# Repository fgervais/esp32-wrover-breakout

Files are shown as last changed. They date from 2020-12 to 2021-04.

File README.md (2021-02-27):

# Objective

The goal of this project is to make a lower cost esp32 module than the TinyPICO
for my other projects.

The TinyPICO is great. It is small and uses low current in deep sleep but it
costs me about 40$ CAD once it reaches me. I'd prefer if I could have something
at around 10$ CAD which is the goal of this project.

# Breadboard Version

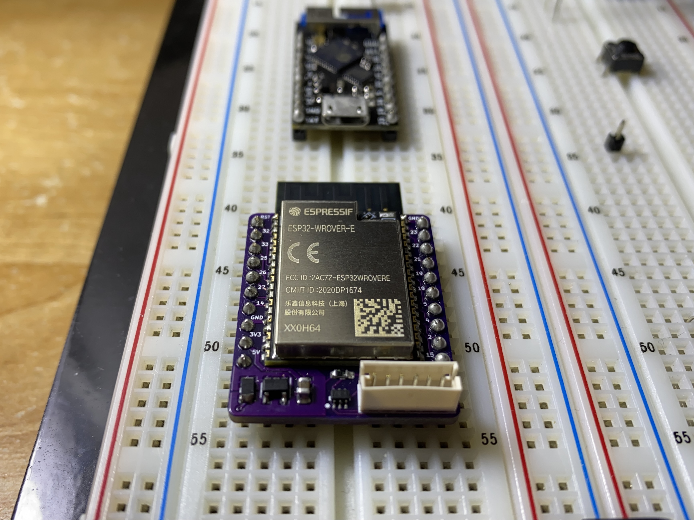
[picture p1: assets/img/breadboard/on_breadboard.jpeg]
On Breadboard


## Price

The bare PCB costs 2.67$ CAD from OSH Park.
Digikey BOM cost for 1 unit is 8.09$ CAD.

Total is 10.76$ CAD (worst case)

## PCB

[OSH Park](https://oshpark.com/shared_projects/hciJOsgc)

## BOM

[Digikey BOM](https://www.digikey.ca/BOM/Create/CreateSharedBom?bomId=8507784)

## Programming

The programming is done through the JST connector using the 
[Adafruit 3309](https://www.adafruit.com/product/3309) along
with the following adapter:

- [Github](https://github.com/fgervais/project-adafruit-3309-adapter/tree/master/hardware/jst-zh)
- [OSH Park](https://oshpark.com/shared_projects/B9to99oI)

### Firmware

The GENERIC-SPIRAM firmware can be downloaded from the following page:

https://micropython.org/download/esp32/

The module has been validated to work with:

esp32spiram-idf4-20210202-v1.14.bin

# M.2 Version

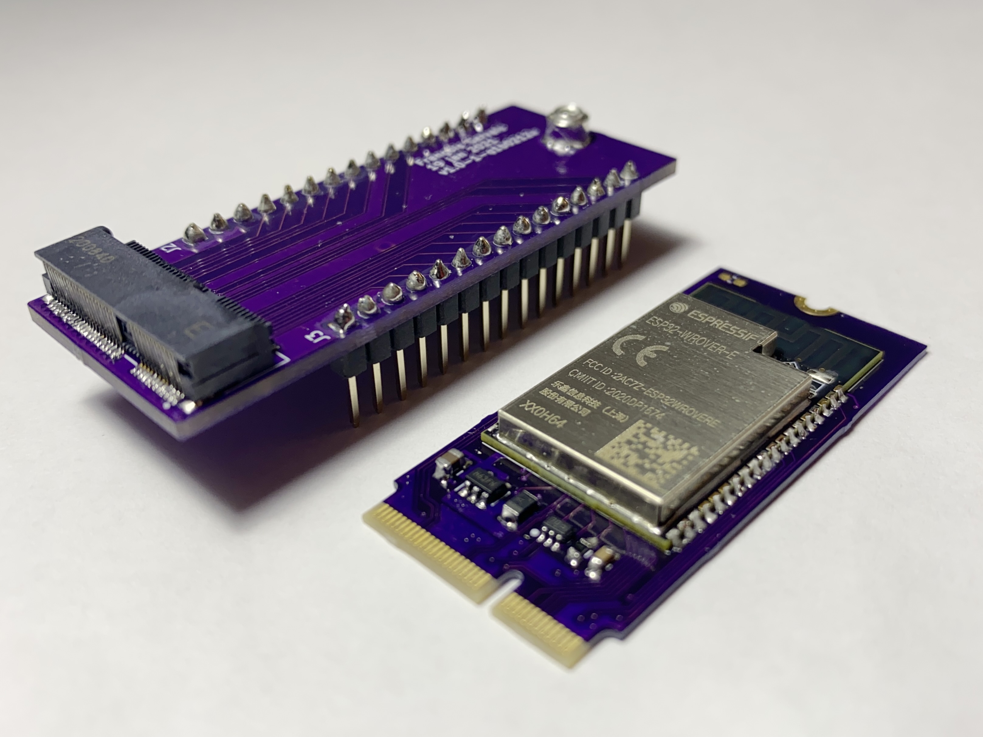
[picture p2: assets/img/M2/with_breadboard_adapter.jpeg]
With Breadboard Adapter


## Price

Bare PCB (OSH Park): 3.47$ CAD
BOM (Digikey, 1 unit): 7.84$ CAD

Total: 11.31$ CAD (worst case)

## BOM

[Digikey BOM](https://www.digikey.ca/BOM/Create/CreateSharedBom?bomId=8549197)

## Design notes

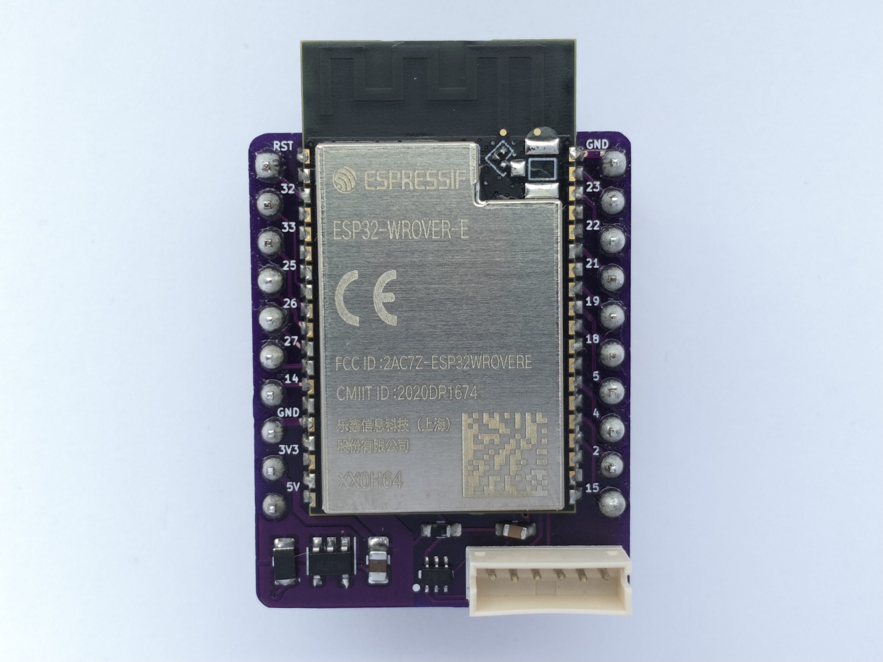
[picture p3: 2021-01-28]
assets/img/breadboard/populated.jpeg

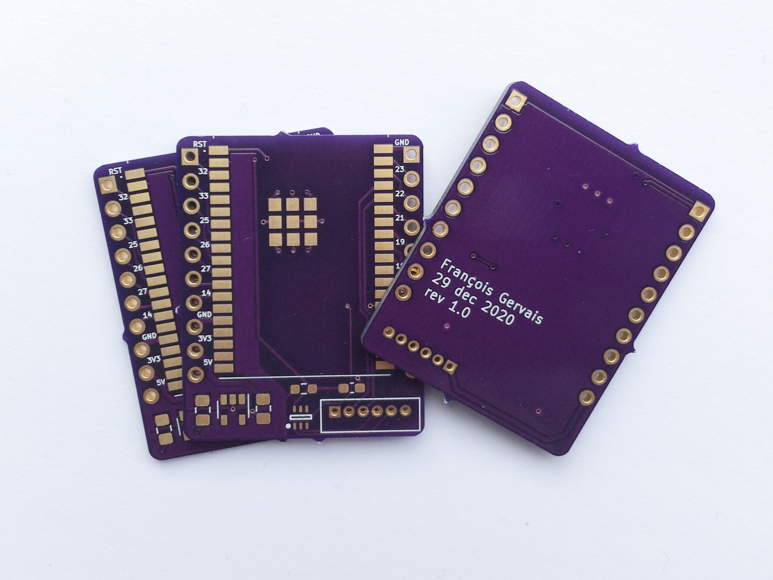
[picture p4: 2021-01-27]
assets/img/breadboard/bare_pcbs.jpeg

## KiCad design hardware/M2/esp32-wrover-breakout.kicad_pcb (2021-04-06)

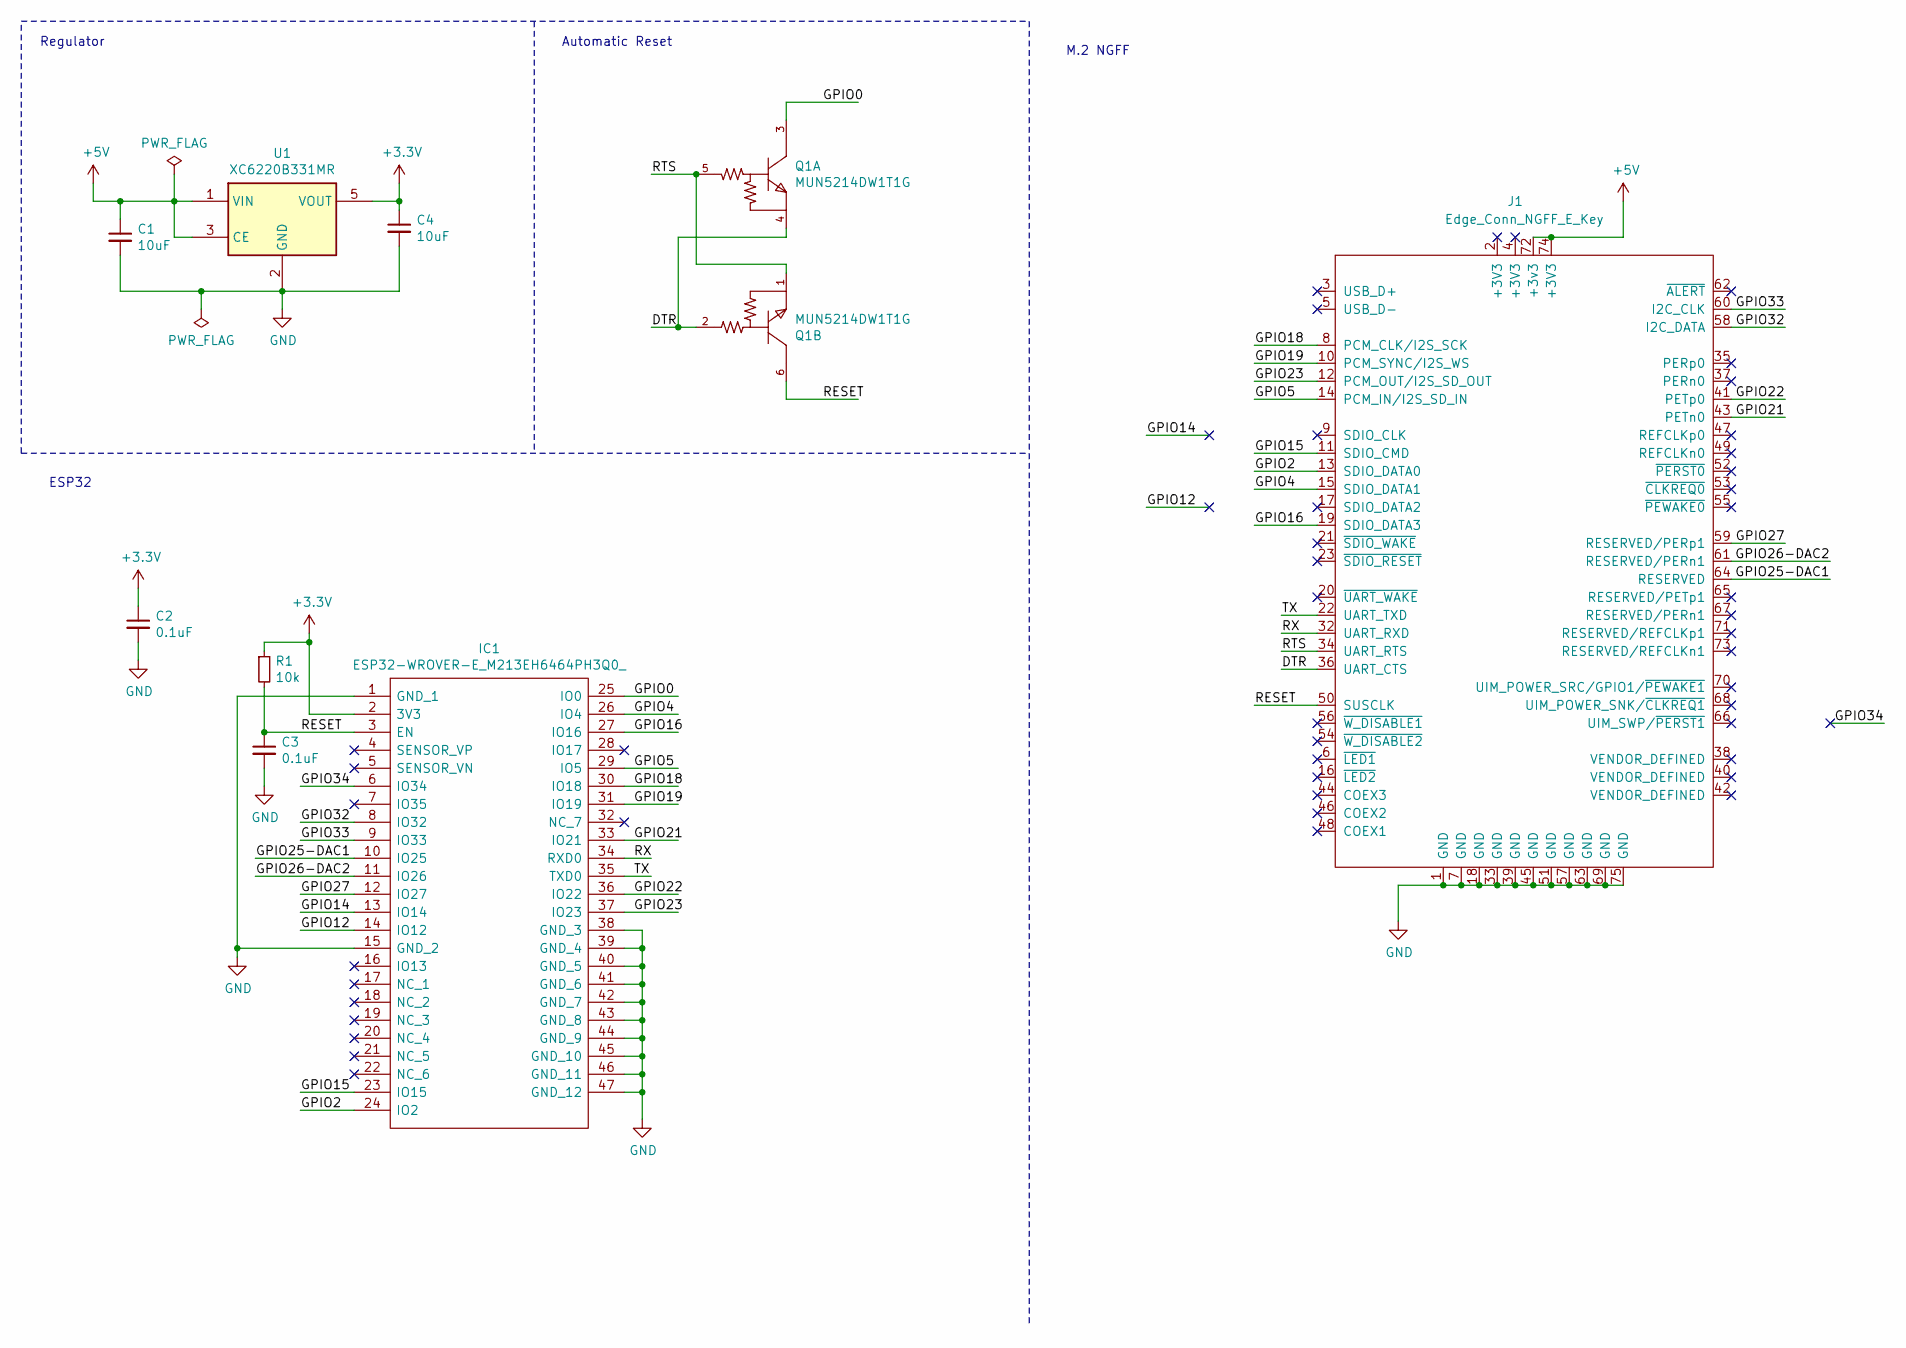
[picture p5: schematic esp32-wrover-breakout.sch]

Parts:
C1, C4: 10uF; C_0805_2012Metric_Pad1.18x1.45mm_HandSolder
C2, C3: 0.1uF; C_0603_1608Metric_Pad1.08x0.95mm_HandSolder
IC1: ESP32-WROVER-E_M213EH6464PH3Q0_; ESP32WROVEREM213EH6464PH3Q0; Manufacturer_Part_Number ESP32-WROVER-E(M213EH6464PH3Q0); Mouser Part Number 356-ESP32WRVE26464PC
J1: Edge_Conn_NGFF_E_Key; NGFF_E
Q1: MUN5214DW1T1G; On_Semiconductor-MUN5214DW1T1G-Manufacturer_Recommended
R1: 10k; R_0603_1608Metric_Pad0.98x0.95mm_HandSolder
U1: XC6220B331MR; SOT-23-5

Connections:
+3V3: C2.1, C4.1, IC1.2 (3V3), R1.1, U1.5 (VOUT)
+5V: C1.1, J1.72 (+3v3), J1.74 (+3V3), U1.1 (VIN), U1.3 (CE)
/DTR: J1.36 (UART_CTS), Q1.2 (B), Q1.4 (E)
/GPIO0: IC1.25 (IO0), Q1.3 (C)
/GPIO2: IC1.24 (IO2), J1.13 (SDIO_DATA0)
/GPIO4: IC1.26 (IO4), J1.15 (SDIO_DATA1)
/GPIO5: IC1.29 (IO5), J1.14 (PCM_IN/I2S_SD_IN)
/GPIO12: IC1.14 (IO12)
/GPIO14: IC1.13 (IO14)
/GPIO15: IC1.23 (IO15), J1.11 (SDIO_CMD)
/GPIO16: IC1.27 (IO16), J1.19 (SDIO_DATA3)
/GPIO18: IC1.30 (IO18), J1.8 (PCM_CLK/I2S_SCK)
/GPIO19: IC1.31 (IO19), J1.10 (PCM_SYNC/I2S_WS)
/GPIO21: IC1.33 (IO21), J1.43 (PETn0)
/GPIO22: IC1.36 (IO22), J1.41 (PETp0)
/GPIO23: IC1.37 (IO23), J1.12 (PCM_OUT/I2S_SD_OUT)
/GPIO25-DAC1: IC1.10 (IO25), J1.64 (RESERVED)
/GPIO26-DAC2: IC1.11 (IO26), J1.61 (RESERVED/PERn1)
/GPIO27: IC1.12 (IO27), J1.59 (RESERVED/PERp1)
/GPIO32: IC1.8 (IO32), J1.58 (I2C_DATA)
/GPIO33: IC1.9 (IO33), J1.60 (I2C_CLK)
/GPIO34: IC1.6 (IO34)
/RESET: C3.1, IC1.3 (EN), J1.50 (SUSCLK), Q1.6 (C), R1.2
/RTS: J1.34 (UART_RTS), Q1.1 (E), Q1.5 (B)
/RX: IC1.34 (RXD0), J1.32 (UART_RXD)
/TX: IC1.35 (TXD0), J1.22 (UART_TXD)
GND: C1.2, C2.2, C3.2, C4.2, IC1.1 (GND_1), IC1.15 (GND_2), IC1.38 (GND_3), IC1.39 (GND_4), IC1.40 (GND_5), IC1.41 (GND_6), IC1.42 (GND_7), IC1.43 (GND_8), IC1.44 (GND_9), IC1.45 (GND_10), IC1.46 (GND_11), IC1.47 (GND_12), J1.1 (GND), J1.7 (GND), J1.18 (GND), J1.33 (GND), J1.39 (GND), J1.45 (GND), J1.51 (GND), J1.57 (GND), J1.63 (GND), J1.69 (GND), J1.75 (GND), U1.2 (GND)

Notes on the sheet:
Automatic Reset
Regulator
M.2 NGFF
ESP32

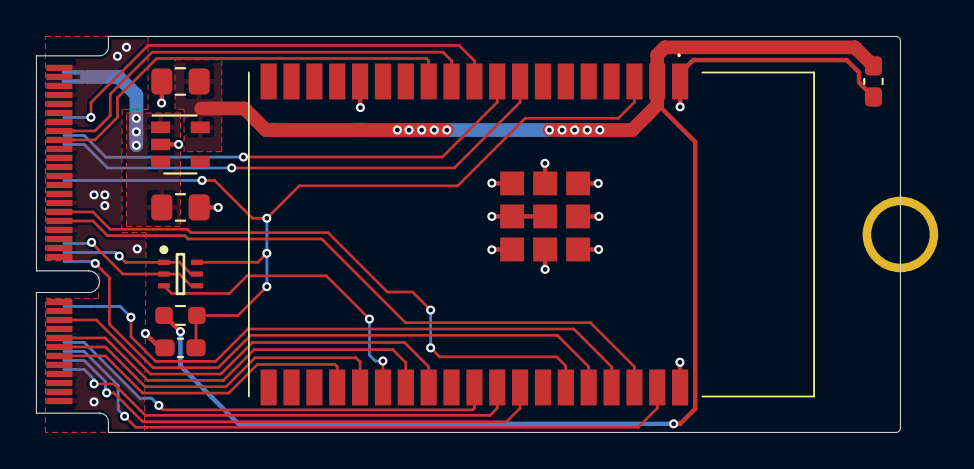
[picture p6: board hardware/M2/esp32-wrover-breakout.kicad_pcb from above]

Board: 2 copper layers, 48.0 x 22.0 mm, 9 parts (0 on the bottom side), 24 nets.

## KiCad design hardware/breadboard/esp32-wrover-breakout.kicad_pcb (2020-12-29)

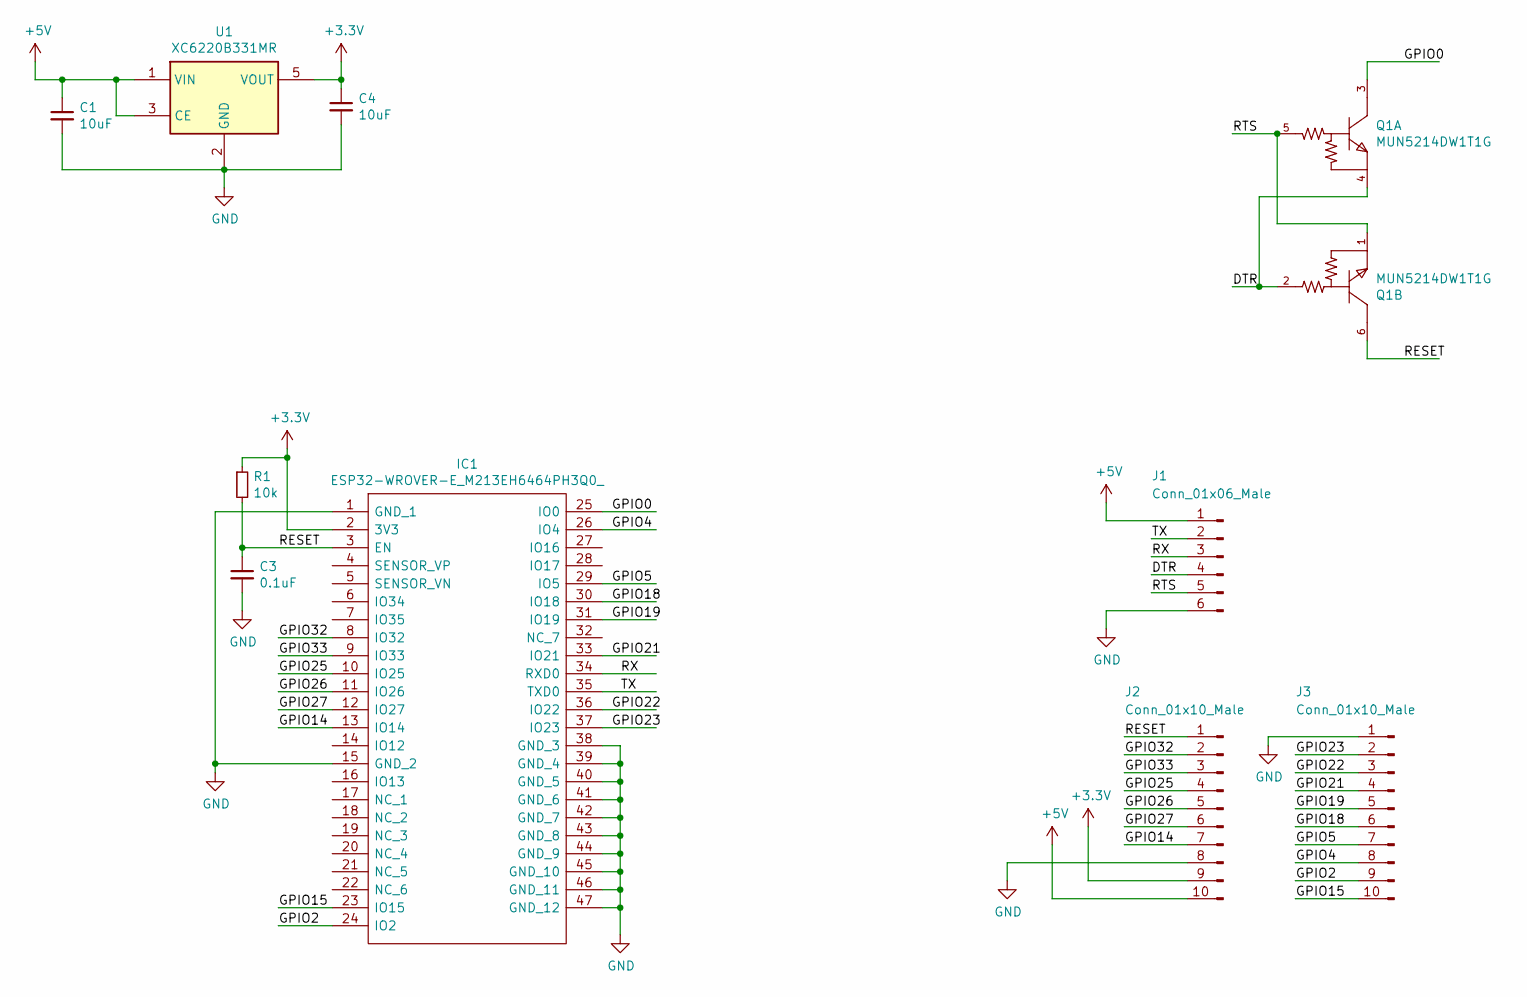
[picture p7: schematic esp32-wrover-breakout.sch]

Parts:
C1, C4: 10uF; C_0805_2012Metric_Pad1.18x1.45mm_HandSolder
C3: 0.1uF; C_0603_1608Metric_Pad1.08x0.95mm_HandSolder
IC1: ESP32-WROVER-E_M213EH6464PH3Q0_; ESP32WROVEREM213EH6464PH3Q0; Manufacturer_Part_Number ESP32-WROVER-E(M213EH6464PH3Q0); Mouser Part Number 356-ESP32WRVE26464PC
J1: Conn_01x06_Male; JST_B6B-ZR(LF)(SN)
J2, J3: Conn_01x10_Male; PinHeader_1x10_P2.54mm_Vertical
Q1: MUN5214DW1T1G; On_Semiconductor-MUN5214DW1T1G-Manufacturer_Recommended
R1: 10k; R_0603_1608Metric_Pad0.98x0.95mm_HandSolder
U1: XC6220B331MR; SOT-23-5

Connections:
+3V3: C4.1, IC1.2 (3V3), J2.9, R1.1, U1.5 (VOUT)
+5V: C1.1, J1.1, J2.10, U1.1 (VIN), U1.3 (CE)
/DTR: J1.4, Q1.2 (B), Q1.4 (E)
/GPIO0: IC1.25 (IO0), Q1.3 (C)
/GPIO2: IC1.24 (IO2), J3.9
/GPIO4: IC1.26 (IO4), J3.8
/GPIO5: IC1.29 (IO5), J3.7
/GPIO14: IC1.13 (IO14), J2.7
/GPIO15: IC1.23 (IO15), J3.10
/GPIO18: IC1.30 (IO18), J3.6
/GPIO19: IC1.31 (IO19), J3.5
/GPIO21: IC1.33 (IO21), J3.4
/GPIO22: IC1.36 (IO22), J3.3
/GPIO23: IC1.37 (IO23), J3.2
/GPIO25: IC1.10 (IO25), J2.4
/GPIO26: IC1.11 (IO26), J2.5
/GPIO27: IC1.12 (IO27), J2.6
/GPIO32: IC1.8 (IO32), J2.2
/GPIO33: IC1.9 (IO33), J2.3
/RESET: C3.1, IC1.3 (EN), J2.1, Q1.6 (C), R1.2
/RTS: J1.5, Q1.1 (E), Q1.5 (B)
/RX: IC1.34 (RXD0), J1.3
/TX: IC1.35 (TXD0), J1.2
GND: C1.2, C3.2, C4.2, IC1.1 (GND_1), IC1.15 (GND_2), IC1.38 (GND_3), IC1.39 (GND_4), IC1.40 (GND_5), IC1.41 (GND_6), IC1.42 (GND_7), IC1.43 (GND_8), IC1.44 (GND_9), IC1.45 (GND_10), IC1.46 (GND_11), IC1.47 (GND_12), J1.6, J2.8, J3.1, U1.2 (GND)

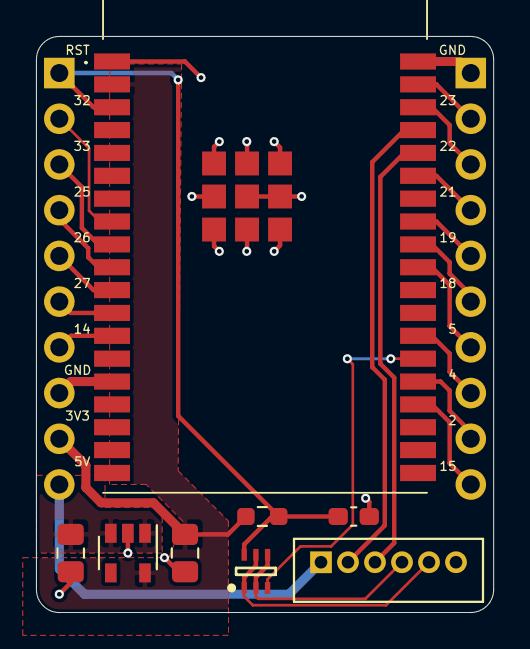
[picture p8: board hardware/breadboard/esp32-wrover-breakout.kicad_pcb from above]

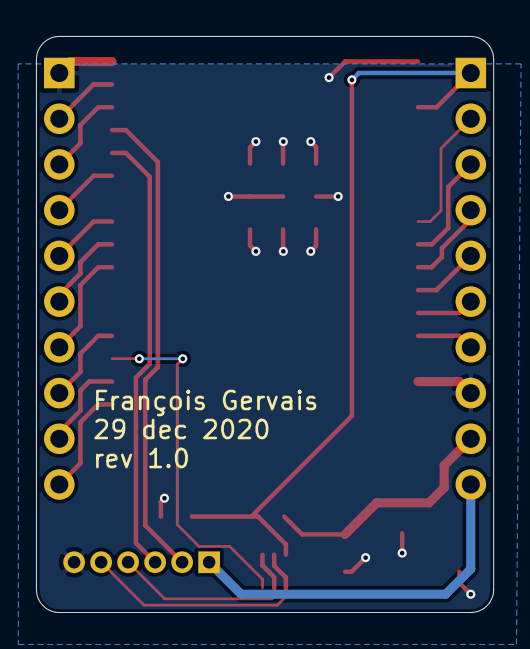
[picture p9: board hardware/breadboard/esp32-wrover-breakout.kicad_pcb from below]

Board: 2 copper layers, 25.4 x 32.0 mm, 10 parts (2 on the bottom side), 24 nets.

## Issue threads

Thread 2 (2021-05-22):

Missing kicad library symbols

fadushin, 2021-05-22:
I am unable to view all symbols in the esp32-rover-breakout.sch schematic.  The `kicad-library` directory appears to be empty on `master`, but the shematic file is searching there for several symbols (such as WROVER)

fgervais, 2021-05-22:
Thank you for you interest in this project @fadushin, it could be because the clone was not recursive, the command would be:

```
git clone --recursive git@github.com:fgervais/esp32-wrover-breakout.git
```

fadushin, 2021-05-23:
Thank you!

Closed 2021-05-23.

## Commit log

2020-12-26 Blank project with ESP module in schematic
    [esp32-wrover-breakout.kicad_pcb, esp32-wrover-breakout.sch]
2020-12-27 Schematic ready
    [esp32-wrover-breakout.sch]
2020-12-28 PCB placement and silkscreen done
    [esp32-wrover-breakout.kicad_pcb, esp32-wrover-breakout.sch]
2020-12-29 First routing done
    [esp32-wrover-breakout.kicad_pcb, esp32-wrover-breakout.sch]
2020-12-29 Rev 1.0
    [esp32-wrover-breakout.kicad_pcb]
2021-01-10 Add an M.2 design cloned from the breadboard one
    [esp32-wrover-breakout.kicad_pcb, esp32-wrover-breakout.sch]
2021-01-12 M.2 schematic + first placement
    [esp32-wrover-breakout.kicad_pcb, esp32-wrover-breakout.sch]
2021-01-14 First M.2 routing
    [esp32-wrover-breakout.kicad_pcb, esp32-wrover-breakout.sch]
2021-01-14 Rotate the screw pad
    [esp32-wrover-breakout.kicad_pcb]
2021-01-14 Remove a little piece of track
    [esp32-wrover-breakout.kicad_pcb]
2021-01-14 A couple finishing touches
    [esp32-wrover-breakout.kicad_pcb]
2021-01-19 Fix forgotten no-connect
    [esp32-wrover-breakout.sch]
2021-01-19 Fix mounting hole size
    Allow for the 3mm bushing.
    [esp32-wrover-breakout.kicad_pcb]
2021-01-28 Add populated board image
2021-01-29 Print the breadboard version
2021-02-11 Add version of previous commit
    [esp32-wrover-breakout.kicad_pcb]
2021-02-16 Add the BOM of the breadboard version
2021-02-16 Add M.2 BOM
2021-02-19 Add a link to the OSH Park board
2021-04-06 Change the mounting hole size
    [esp32-wrover-breakout.kicad_pcb]
